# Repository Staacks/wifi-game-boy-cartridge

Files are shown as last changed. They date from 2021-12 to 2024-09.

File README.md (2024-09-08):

# wifi-game-boy-cartridge
A WiFi cartridge for the original Game Boy.

This open source and open hardware Game Boy cartridge uses an ESP8266 to allow WiFi access for custom Game Boy code. First demos include accessing Wikipedia articles from the Game Boy.

Details and instructions can be found on https://there.oughta.be/a/wifi-game-boy-cartridge and an overview is given in the following video:

Youtube Video: WiFi Game Boy Cartridge (https://youtu.be/QS4fzElm8zk)

Also, another article and video have been published on streaming video through this cartridge, which can be found at https://there.oughta.be/gta5-for-the-game-boy and in this video:

Youtube Video: Playing GTA5 on the original Game Boy (https://youtu.be/pX1opw_gsBs)

If you have pull-requests, bug reports or want to contribute new case designs, please do not hesitate to open an issue. For generic discussions, "show and tell" and if you are looking for support for something that is not a problem in the code here, I would recommend [r/thereoughtabe on reddit](https://www.reddit.com/r/thereoughtabe/).

<a href="https://www.buymeacoffee.com/there.oughta.be" target="_blank">Buy Me A Coffee</a>

# Important notice

Please read the resources above carefully and understand the limitations of this project. The brown-out issues have never been resolved and this is more a prove of concept than a consumer product. If you still want to try it yourself, please also note that rgbasm has changed a lot since this project was written and that its current version is no longer compatible with the asm files provided here. You may need to revert to rgbasm 0.5.2 to build them. 

# Short overview of the demos

As the number of demos keeps growing and some of them are just a quick experiment, you can find a few notes here:

## color-stream

This is the code for streaming videos to the Game Boy Color as shown in [in this little video](https://www.youtube.com/watch?v=kHexmGR_rPY). The code is supposed to detect if the cart is in a classic Game Boy (DMG) or a Game Boy color and both, the EEPROM code as well as the ESP8266 code should react accordingly. However, you have to use the right Python script, i.e. `video-stream` or `game-stream` for the original Game Boy or `color-stream` for a Game Boy color.

Note, that this has not been tested much and still has a few glitches. Also note, that I ran into an ffmpeg problem that prevented me from streaming screen captures on Linux (x11grab).

## serial

The oldest demo from the first video. When this is running, the Game Boy should show your IP address and you can connect to it with a telnet client. You can send text between Game Boy and PC and that's it. Note that there is an error in the way the data pins are initialized, causing them to run in open drain mode, which is ok, except for the highest bit which has an external pull-down and therefore stays low forever. For this demo, it does not matter because the character map does not have anything above the 7bit ASCII map anyways, but if you ever need the eighth bit, look at the streaming videos for how to initialize this correctly.

## stream

The streaming code on which the second video (playing GTA5) is based. It allows to show a video stream on the Game Boy and sends back key presses. You need to feed it with one of the Python scripts, either `video-stream.py` or `game-stream.py`. The buttons seem to generate a few ghost presses, which should be fixed by doing a few more readouts for the buttons (not tested).

## wiki

The Wikipedia demo from the first video. Once it has started, you can press start to get an on-screen keyboard, enter the title of a Wikipedia article and press start again to fetch an excerpt of that article. Pressing A shows you the remainder of the article, if any. Just like with the serial demo above, there is an error in the way the data pins are initialized, causing them to run in open drain mode, which is ok, except for the highest bit which has an external pull-down and therefore stays low forever. For this demo, it does not matter because the character map does not have anything above the 7bit ASCII map anyways, but if you ever need the eighth bit, look at the streaming videos for how to initialize this correctly.

# License
The code and the PCB design are released under the GNU General Public Licence 3. The only exception is the cartridge model for the 3d print, which is based on a [Game Boy cartridge by DomesticHacks on Thingiverse](https://www.thingiverse.com/thing:107841), which is released under a CC-BY-NC-SA license, so I have to publish my derived work under CC-BY-NC-SA, too.

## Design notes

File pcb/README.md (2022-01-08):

# Notes on the PCB design

There are two known possible issues in this design, which you should be aware of when ordering or manufacturing this PCB:
* Some of the 3V3 lines in the top left corner are done es part of an auto-fill area. This works perfectly in KiCad, is properly exported to Gerber files and also passes bug tests with the net list. However, when I ordered from aisler.net where you upload the KiCad file instead of Gerber files, the smaller 3V3 connections were lost. Since this worked in KiCad itself, I think it is a bug in Aisler's renderer, but unfortunately, they did not reply to my questions about this issue.
* I heavily use vias in solder pads. I read that this is bad practice as it might be a problem for automatic manufacturing processes, but fine for hand-soldering. As I did the latter I did not notice any problems, but you should be aware if you use a different process.

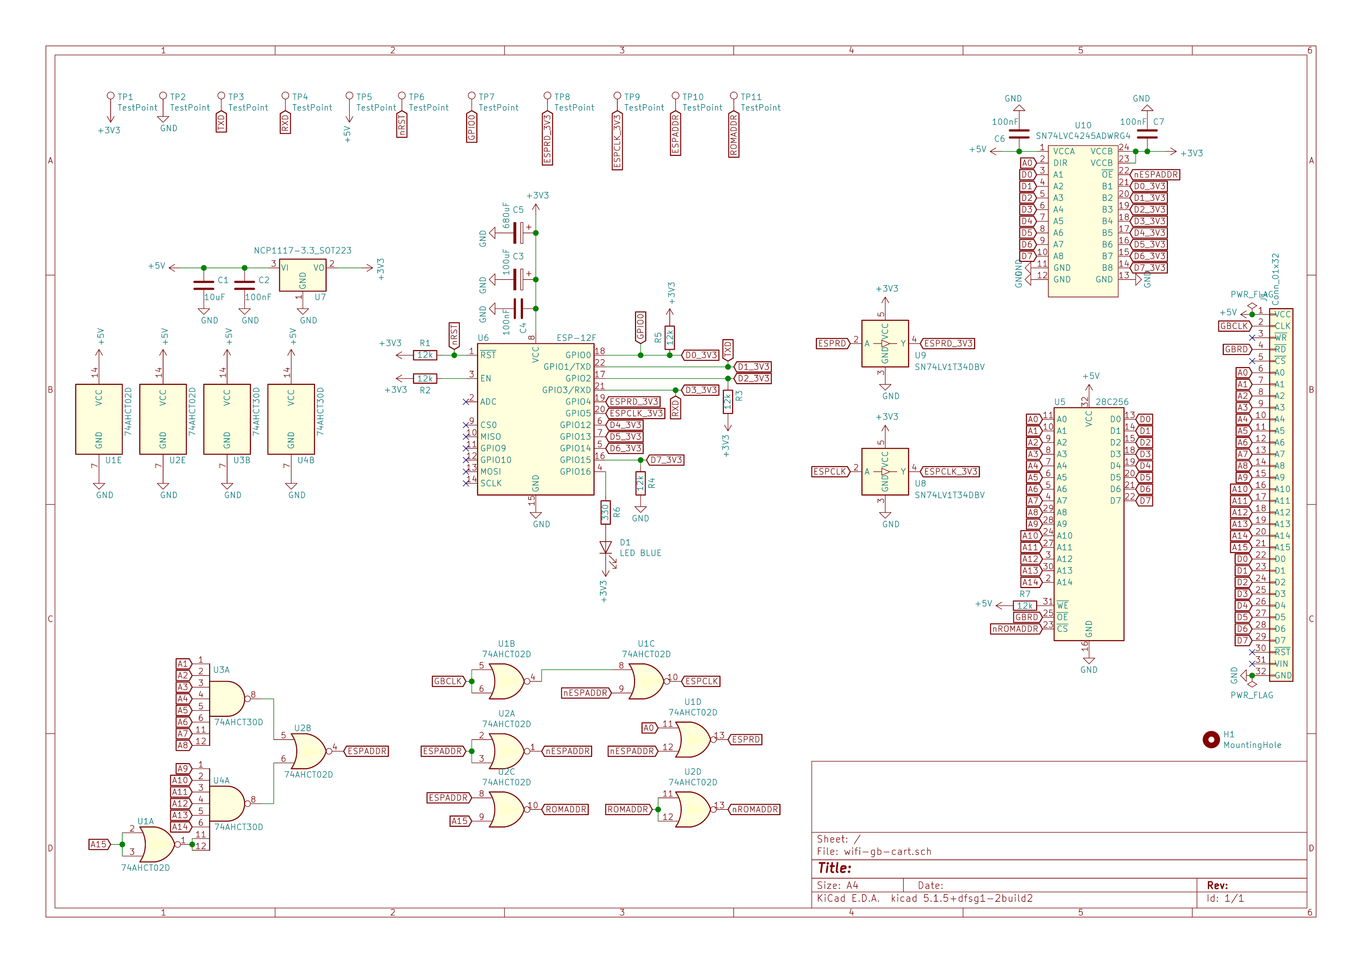
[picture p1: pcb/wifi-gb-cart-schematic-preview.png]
Preview of the schematic


# Licenses
This design is licensed under the GNU General Public License 3.0. See LICENSE file in this directory.

This project includes KiCad libraries and footprints from external sources with following license notices:

## From https://github.com/Gekkio/gb-hardware

This cartridge design uses the connector of Gekkio's GB-CART32K-A design, which is licensed under CC-BY-4.0.

## From https://github.com/adamgreig/agg-kicad

Copyright 2015, 2016 Adam Greig

Permission is hereby granted, free of charge, to any person obtaining a copy of this software and associated documentation files (the "Software"), to deal in the Software without restriction, including without limitation the rights to use, copy, modify, merge, publish, distribute, sublicense, and/or sell copies of the Software, and to permit persons to whom the Software is furnished to do so, subject to the following conditions:

The above copyright notice and this permission notice shall be included in all copies or substantial portions of the Software.

THE SOFTWARE IS PROVIDED "AS IS", WITHOUT WARRANTY OF ANY KIND, EXPRESS OR IMPLIED, INCLUDING BUT NOT LIMITED TO THE WARRANTIES OF MERCHANTABILITY, FITNESS FOR A PARTICULAR PURPOSE AND NONINFRINGEMENT. IN NO EVENT SHALL THE AUTHORS OR COPYRIGHT HOLDERS BE LIABLE FOR ANY CLAIM, DAMAGES OR OTHER LIABILITY, WHETHER IN AN ACTION OF CONTRACT, TORT OR OTHERWISE, ARISING FROM, OUT OF OR IN CONNECTION WITH THE SOFTWARE OR THE USE OR OTHER DEALINGS IN THE SOFTWARE.

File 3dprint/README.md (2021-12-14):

# Print parameters
I printed this with 0.1mm layer height with plain white PLA without supports.

# License
This model is based on a [Game Boy cartridge by DomesticHacks on Thingiverse](https://www.thingiverse.com/thing:107841) and accordingly retains a [CC-BY-NC-SA 4.0 licence](https://creativecommons.org/licenses/by-nc-sa/4.0/).

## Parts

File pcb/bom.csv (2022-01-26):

Query | Qty | Manufacturer | MPN | Octopart URL | Part Description | Description | Schematic Reference | Internal Part Number | Lifecycle | Lead Time | RoHS | Total Qty (@ Batch Size: 1) | SKU | SKU | SKU | SKU | SKU | Packaging | Packaging | Packaging | Packaging | Packaging | Unit Price (@ Batch Size: 1) | Unit Price (@ Batch Size: 1) | Unit Price (@ Batch Size: 1) | Unit Price (@ Batch Size: 1) | Unit Price (@ Batch Size: 1) | In Stock | In Stock | In Stock | In Stock | In Stock | MOQ | MOQ | MOQ | MOQ | MOQ | URL | URL | URL | URL | URL | Distributor [Lowest Price (Selected)] | SKU [Lowest Price (Selected)] | Packaging [Lowest Price (Selected)] | Unit Price (@ Batch Size: 1) [Lowest Price (Selected)] | Line Total [Lowest Price (Selected)] | Batch Total [Lowest Price (Selected)] | In Stock [Lowest Price (Selected)] | MOQ [Lowest Price (Selected)] | URL [Lowest Price (Selected)] | Notes
 |  |  |  |  |  |  |  |  |  |  |  |  | Digi-Key | Mouser | Newark | Onlinecomponents.com | RS Components | Digi-Key | Mouser | Newark | Onlinecomponents.com | RS Components | Digi-Key | Mouser | Newark | Onlinecomponents.com | RS Components | Digi-Key | Mouser | Newark | Onlinecomponents.com | RS Components | Digi-Key | Mouser | Newark | Onlinecomponents.com | RS Components | Digi-Key | Mouser | Newark | Onlinecomponents.com | RS Components
69802-432LF | 1 | Amphenol ICC / FCI | 69802-432LF | https://octopart.com/69802-432lf-amphenol+icc+%2F+fci-90340517 | Conn PLCC Socket SKT 32 POS 1.27mm Solder ST SMD T/R |  |  |  |  | 12w | Compliant | 1 | 609-4532-1-ND | 649-69802-432LF | 16M2200 | 69802-432LF | 1822967 | Cut Tape | Tape & Reel |  | Bulk |  | 1.68 | 1.66 | 0.541 |  |  | 3355 | 4990 | 424 | 4006 | 1617 | 1 | 1 | 1 | 390 | 5 | https://octopart.com/click/track?ai4=706&country=DE&ct=offers&ppid=90340517&sid=459&sig=0924f15&vpid=531335192 | https://octopart.com/click/track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 | https://octopart.com/click/track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 | https://octopart.com/click/track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 | https://octopart.com/click/track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 | Newark | 16M2200 |  | 0.541 | 0.541 | 0.541 | 424 | 1 | https://octopart.com/click/track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
AT28C256-15JU | 1 | Microchip | AT28C256-15JU | https://octopart.com/at28c256-15ju-microchip-77758239 | AT28C256-15JU Parallel EEPROM Memory, 256kbit, 150ns, 4.5 to 5.5 V 32-Pin PLCC |  |  |  | Production (Last Updated: 1 year ago) | 52w | Compliant | 1 | AT28C256-15JU-ND | 556-AT28C25615JU | 68T4337 | AT28C256-15JU | 1276569 | Tube | Tube |  | Bulk |  | 10.45 | 10.46 |  |  | 9.70502370395615 | 0 | 15 | 0 | 0 | 188 | 1 | 1 | 64 | 32 | 1 | https://octopart.com/click/track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 | https://octopart.com/click/track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 | https://octopart.com/click/track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 | https://octopart.com/click/track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 | https://octopart.com/click/track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 | RS Components | 1276569 |  | 9.70502370395615 | 9.70502370395615 | 9.70502370395615 | 188 | 1 | https://octopart.com/click/track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
74AHCT30D-Q100J | 2 | Nexperia | 74AHCT30D-Q100J | https://octopart.com/74ahct30d-q100j-nexperia-78749832 | 74AHCT Series 5 V Surface Mount 8-Input NAND Gate - SOIC-14 |  |  |  | Production (Last Updated: 18 hours ago) | 52w | Compliant | 2 | 74AHCT30D-Q100J-ND | 771-74AHCT30DQ100J |  |  |  | Tape & Reel | Tape & Reel |  |  |  |  | 0.65 |  |  |  | 0 | 623 |  |  |  | 2500 | 1 |  |  |  | https://octopart.com/click/track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 | https://octopart.com/click/track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 |  |  |  | Mouser | 771-74AHCT30DQ100J | Tape & Reel | 0.65 | 1.3 | 1.3 | 623 | 1 | https://octopart.com/click/track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
SN74AHCT02D | 2 | Texas Instruments | SN74AHCT02D | https://octopart.com/sn74ahct02d-texas+instruments-465348 | 4-ch, 2-input, 4.5-V to 5.5-V NOR gates with TTL-compatible CMOS inputs 14-SOIC -40 to 85 |  |  |  | Production (Last Updated: 1 week ago) | 6w | Compliant | 2 | 296-4634-5-ND | 595-SN74AHCT02D | 26AJ9118 |  |  | Tube | Tube |  |  |  | 1.16 | 1.15 | 1.78 |  |  | 343 | 968 | 0 |  |  | 1 | 1 | 1 |  |  | https://octopart.com/click/track?ai4=706&country=DE&ct=offers&ppid=465348&sid=459&sig=054b0ee&vpid=1996635 | https://octopart.com/click/track?ai4=706&country=DE&ct=offers&ppid=465348&sid=2401&sig=049629f&vpid=37843758 | https://octopart.com/click/track?ai4=706&country=DE&ct=offers&ppid=465348&sid=2402&sig=0316a07&vpid=702462753 |  |  | Mouser | 595-SN74AHCT02D | Tube | 1.15 | 2.3 | 2.3 | 968 | 1 | https://octopart.com/click/track?ai4=706&country=DE&ct=offers&ppid=465348&sid=2401&sig=049629f&vpid=37843758
RC1206FR-0712KL | 6 | Yageo | RC1206FR-0712KL | https://octopart.com/rc1206fr-0712kl-yageo-41455584 | Res Thick Film 1206 12K Ohm 1% 0.25W(1/4W) ±100ppm/C Pad SMD T/R |  |  |  |  | 20w | Compliant | 6 | 311-12.0KFRCT-ND | 603-RC1206FR-0712KL | 98K7634 |  |  | Cut Tape | Tape & Reel |  |  |  | 0.1 | 0.1 |  |  |  | 98698 | 24846 | 0 |  |  | 1 | 1 | 10 |  |  | https://octopart.com/click/track?ai4=706&country=DE&ct=offers&ppid=41455584&sid=459&sig=033d2b6&vpid=115263624 | https://octopart.com/click/track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 | https://octopart.com/click/track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 |  |  | Digi-Key | 311-12.0KFRCT-ND | Cut Tape | 0.1 | 0.6000000000000001 | 0.6000000000000001 | 98698 | 1 | https://octopart.com/click/track?ai4=706&country=DE&ct=offers&ppid=41455584&sid=459&sig=033d2b6&vpid=115263624
C1206C106K8PAC | 1 | KEMET | C1206C106K8PACTU | https://octopart.com/c1206c106k8pactu-kemet-8342310 | 1206 C 10uF Ceramic Multilayer Capacitor; 10 VDC; +85degC; X5R Dielec; +/-10% |  |  |  |  | 24w | Compliant | 1 | 399-C1206C106K8PAC7800CT-ND | 80-C1206C106K8P | 96K8340 | C1206C106K8PACTU | 148092P | Cut Tape | Tape & Reel |  | Bulk |  | 0.35 | 0.31 |  |  |  | 73059 | 17299 | 7660 | 0 | 29225 | 1 | 1 | 5 | 32 | 250 | https://octopart.com/click/track?ai4=706&country=DE&ct=offers&ppid=8342310&sid=459&sig=032318f&vpid=778087788 | https://octopart.com/click/track?ai4=706&country=DE&ct=offers&ppid=8342310&sid=2401&sig=0a64551&vpid=37843845 | https://octopart.com/click/track?ai4=706&country=DE&ct=offers&ppid=8342310&sid=2402&sig=030086b&vpid=73976561 | https://octopart.com/click/track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 | https://octopart.com/click/track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 | Mouser | 80-C1206C106K8P | Tape & Reel | 0.31 | 0.31 | 0.31 | 17299 | 1 | https://octopart.com/click/track?ai4=706&country=DE&ct=offers&ppid=8342310&sid=2401&sig=0a64551&vpid=37843845
C1206C104M5RACTU | 4 | KEMET | C1206C104M5RACTU | https://octopart.com/c1206c104m5ractu-kemet-129344 | 1206 C 100nF Ceramic Multilayer Capacitor; 50 VDC; +125degC; X7R Dielec; +/-20% |  |  |  |  | 52w | Compliant | 4 | 399-C1206C104M5RAC7800CT-ND | 80-C1206C104M5R | 14N2184 | C1206C104M5RACTU | 2053277 | Cut Tape | Tape & Reel |  | Bulk |  | 0.12 | 0.1 | 0.008 |  |  | 69939 | 49947 | 2519 | 0 | 2600 | 1 | 1 | 1 | 8000 | 100 | https://octopart.com/click/track?ai4=706&country=DE&ct=offers&ppid=129344&sid=459&sig=0316d49&vpid=778087758 | https://octopart.com/click/track?ai4=706&country=DE&ct=offers&ppid=129344&sid=2401&sig=09e4eaf&vpid=44737023 | https://octopart.com/click/track?ai4=706&country=DE&ct=offers&ppid=129344&sid=2402&sig=0e80658&vpid=16453344 | https://octopart.com/click/track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 | https://octopart.com/click/track?ai4=706&country=DE&ct=offers&ppid=129344&sid=10022&sig=02caed9&vpid=694088864 | Newark | 14N2184 |  | 0.008 | 0.032 | 0.032 | 2519 | 1 | https://octopart.com/click/track?ai4=706&country=DE&ct=offers&ppid=129344&sid=2402&sig=0e80658&vpid=16453344
SN74LVC4245ADWRG4 | 1 | Texas Instruments | SN74LVC4245ADWRG4 | https://octopart.com/sn74lvc4245adwrg4-texas+instruments-7119357 | Octal Bus Transceiver And 3.3-V To 5-V Shifter With 3-State Outputs 24-SOIC -40 to 85 |  |  |  | Production (Last Updated: 1 week ago) | 20w | Compliant | 1 | 296-48964-1-ND | 595-74LVC4245ADWRG4 |  |  |  | Cut Tape | Tape & Reel |  |  |  | 1.64 | 1.64 |  |  |  | 1145 | 191 |  |  |  | 1 | 1 |  |  |  | https://octopart.com/click/track?ai4=706&country=DE&ct=offers&ppid=7119357&sid=459&sig=031f038&vpid=477161524 | https://octopart.com/click/track?ai4=706&country=DE&ct=offers&ppid=7119357&sid=2401&sig=09ef8d3&vpid=94925989 |  |  |  | Digi-Key | 296-48964-1-ND | Cut Tape | 1.64 | 1.64 | 1.64 | 1145 | 1 | https://octopart.com/click/track?ai4=706&country=DE&ct=offers&ppid=7119357&sid=459&sig=031f038&vpid=477161524
SN74LV1T34DBVRG4 | 2 | Texas Instruments | SN74LV1T34DBVRG4 | https://octopart.com/sn74lv1t34dbvrg4-texas+instruments-91780194 | Single Power Supply BUFFER Logic Level Shifter (no enable) 5-SOT-23 -40 to 125 |  |  |  | Production (Last Updated: 1 week ago) | 35w | Non-Compliant | 2 | 296-SN74LV1T34DBVRG4DKR-ND | 595-SN74LV1T34DBVRG4 |  |  |  | Custom Reel | Tape & Reel |  |  |  | 0.64 | 0.64 |  |  |  | 0 | 3 |  |  |  | 1 | 1 |  |  |  | https://octopart.com/click/track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 | https://octopart.com/click/track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 |  |  |  | Mouser | 595-SN74LV1T34DBVRG4 | Tape & Reel | 0.64 | 1.28 | 1.28 | 3 | 1 | https://octopart.com/click/track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
NCP1117IST33T3G | 1 | onsemi | NCP1117IST33T3G | https://octopart.com/ncp1117ist33t3g-onsemi-117063396 | LDO Regulator, 1 A, Fixed and Adjustable, Positive Vout: 3.3 V |  |  |  |  | 48w |  | 1 | 488-NCP1117IST33T3GCT-ND | 863-NCP1117IST33T3G | 50AJ5825 |  | 2296355 | Cut Tape | Tape & Reel |  |  |  | 0.6 | 0.6 |  |  |  | 0 | 0 | 3975 |  | 0 | 1 | 1 | 5 |  | 10 | https://octopart.com/click/track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 | https://octopart.com/click/track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 | https://octopart.com/click/track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 |  | https://octopart.com/click/track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 | Digi-Key | 488-NCP1117IST33T3GCT-ND | Cut Tape | 0.6 | 0.6 | 0.6 | 0 | 1 | https://octopart.com/click/track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
5015 | 7 | Keystone | 5015 | https://octopart.com/5015-keystone-3822 | MS27478 - Connectors Receptacle Electrical Solder Mounting Solder Type Hermetic Seal 38999 Series II |  |  |  |  | 12w | Compliant | 7 | 36-5015CT-ND | 534-5015 | 50B4581 |  |  | Cut Tape | Tape & Reel |  |  |  | 0.45 | 0.45 | 0.67 |  |  | 5192104 | 2055416 | 11335 |  |  | 1 | 1 | 1 |  |  | https://octopart.com/click/track?ai4=706&country=DE&ct=offers&ppid=3822&sid=459&sig=04fb0c0&vpid=212427660 | https://octopart.com/click/track?ai4=706&country=DE&ct=offers&ppid=3822&sid=2401&sig=0e2f561&vpid=37763329 | https://octopart.com/click/track?ai4=706&country=DE&ct=offers&ppid=3822&sid=2402&sig=0b853ff&vpid=2982736 |  |  | Digi-Key | 36-5015CT-ND | Cut Tape | 0.45 | 3.15 | 3.15 | 5192104 | 1 | https://octopart.com/click/track?ai4=706&country=DE&ct=offers&ppid=3822&sid=459&sig=04fb0c0&vpid=212427660
TAJE687M010RNJV | 1 | KYOCERA AVX | TAJE687M010RNJV | https://octopart.com/taje687m010rnjv-kyocera+avx-122089020 | Cap Tant Solid 680uF 10V E CASE 20% (7.3 X 4.3 X 4.1mm) Inward L SMD 7343-43 0.4 Ohm 125C T/R |  |  |  | Production (Last Updated: 2 years ago) | 35w | Non-Compliant | 1 | 478-TAJE687M010RNJVTR-ND | 581-TAJE687M010RNJV | 13AC9452 |  |  | Tape & Reel | Tape & Reel |  |  |  |  | 3.7 |  |  |  | 0 | 0 | 0 |  |  | 400 | 1 | 400 |  |  | https://octopart.com/click/track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 | https://octopart.com/click/track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 | https://octopart.com/click/track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 |  |  | Mouser | 581-TAJE687M010RNJV | Tape & Reel | 3.7 | 3.7 | 3.7 | 0 | 1 | https://octopart.com/click/track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
TAJB107M010RNJ | 1 | AVX | TAJB107M010RNJ | https://octopart.com/tajb107m010rnj-avx-10552444 | Cap Tant Solid 100uF 10V B CASE 20% (3.5 X 2.8 X 1.9mm) SMD 3528-21 1.4 Ohm 125A HA T/R |  |  |  | Production (Last Updated: 2 years ago) | 30w | Compliant | 1 | 478-5801-1-ND | 581-TAJB107M010R | 15P3056 |  | 1360118 | Cut Tape | Tape & Reel |  |  |  | 0.62 | 0.82 |  |  |  | 0 | 0 | 0 |  | 960 | 1 | 1 | 5 |  | 20 | https://octopart.com/click/track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 | https://octopart.com/click/track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 | https://octopart.com/click/track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 |  | https://octopart.com/click/track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 | Digi-Key | 478-5801-1-ND | Cut Tape | 0.62 | 0.62 | 0.62 | 0 | 1 | https://octopart.com/click/track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
CRGCQ1206J330R | 1 | TE Connectivity | CRGCQ1206J330R | https://octopart.com/crgcq1206j330r-te+connectivity-91018326 | Res Thick Film 1206 330 Ohm 5% 0.25W(1/4W) ±100ppm/C Pad SMD Automotive T/R |  |  |  | Production (Last Updated: 1 week ago) | 21w | Compliant | 1 | A130174CT-ND | 279-CRGCQ1206J330R | 61AC6733 | CRGCQ1206J330R |  | Cut Tape | Tape & Reel |  | Bulk |  | 0.1 | 0.1 | 0.029 |  |  | 33157 | 3438 | 3180 | 0 |  | 1 | 1 | 1 | 5000 |  | https://octopart.com/click/track?ai4=706&country=DE&ct=offers&ppid=91018326&sid=459&sig=0358dc5&vpid=475509225 | https://octopart.com/click/track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 | https://octopart.com/click/track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 | https://octopart.com/click/track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 |  | Newark | 61AC6733 |  | 0.029 | 0.029 | 0.029 | 3180 | 1 | https://octopart.com/click/track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
156120BS75000 | 1 | Würth Elektronik | 156120BS75000 | https://octopart.com/156120bs75000-w%C3%BCrth+elektronik-71241453 | Led, Blue, 50MCD, 470NM, 1206 |  |  |  |  | 23w | Non-Compliant | 1 | 732-11418-1-ND | 710-156120BS75000 | 22AC3288 |  | 9008921P | Cut Tape | Tape & Reel |  |  |  | 0.35 | 0.35 | 0.398 |  |  | 5492 | 719 | 1214 |  | 1500 | 1 | 1 | 1 |  | 250 | https://octopart.com/click/track?ai4=706&country=DE&ct=offers&ppid=71241453&sid=459&sig=04af43a&vpid=423421451 | https://octopart.com/click/track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 | https://octopart.com/click/track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 |  | https://octopart.com/click/track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 | Digi-Key | 732-11418-1-ND | Cut Tape | 0.35 | 0.35 | 0.35 | 5492 | 1 | https://octopart.com/click/track?ai4=706&country=DE&ct=offers&ppid=71241453&sid=459&sig=04af43a&vpid=423421451
ESP-12F | 1 | Ai-Thinker | ESP-12F | https://octopart.com/esp-12f-ai-thinker-121417371 |  |  |  |  |  |  |  | 1

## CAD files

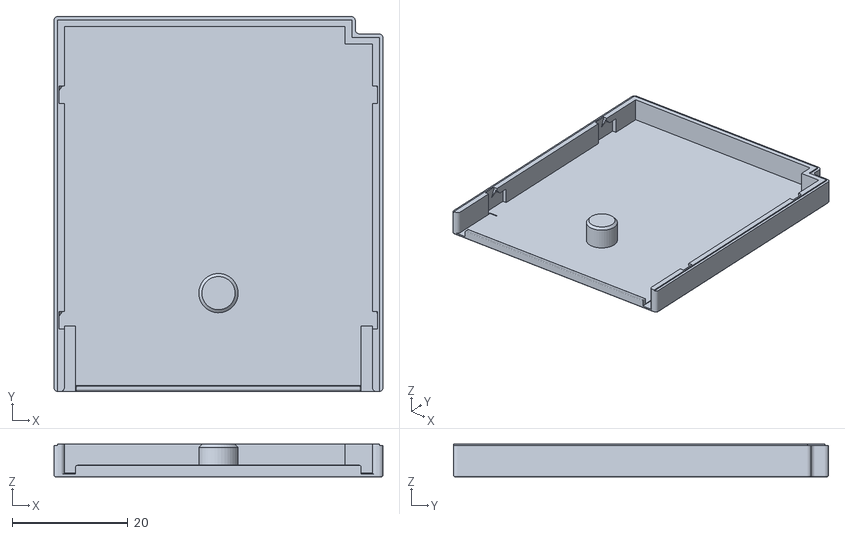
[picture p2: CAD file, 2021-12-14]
3dprint/bottom.stl
56.9 x 64.8 x 5.70

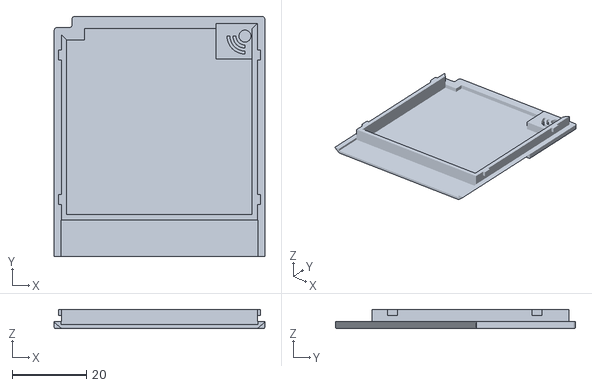
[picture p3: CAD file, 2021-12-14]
3dprint/top.stl
56.9 x 64.8 x 5.14

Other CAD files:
3dprint/bottom.blend
3dprint/top.blend

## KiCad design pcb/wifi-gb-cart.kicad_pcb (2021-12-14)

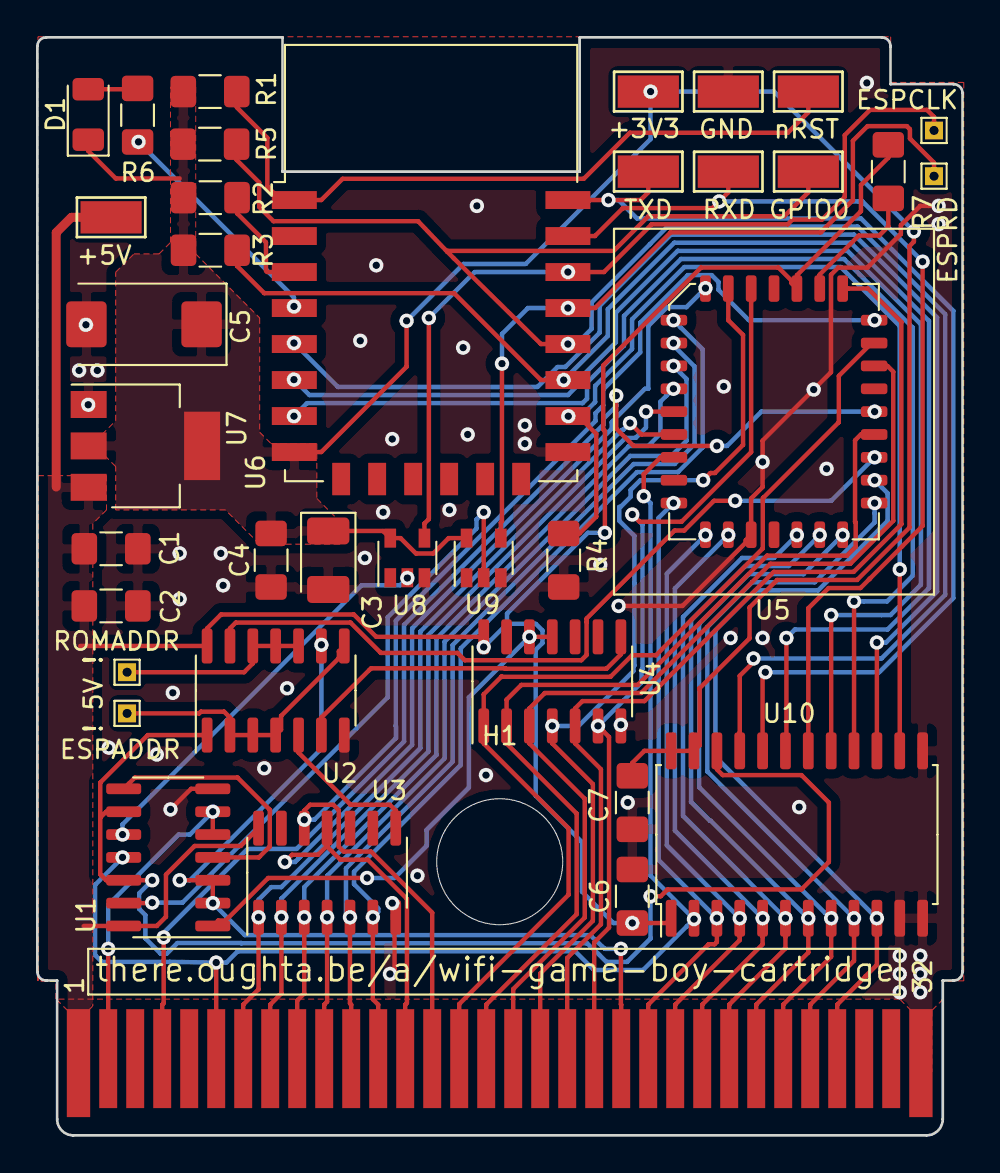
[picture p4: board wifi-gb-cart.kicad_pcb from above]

Board: 2 copper layers, 51.4 x 61.0 mm, 38 parts (0 on the bottom side), 54 nets.

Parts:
+3V3, +5V: TestPoint; TestPoint_Keystone_5015_Micro-Minature
C1: 10uF; C_1206_3216Metric_Pad1.42x1.75mm_HandSolder
C2, C4, C6, C7: 100nF; C_1206_3216Metric_Pad1.42x1.75mm_HandSolder
C3: 100uF; CP_EIA-3528-12_Kemet-T_Pad1.50x2.35mm_HandSolder
C5: 680uF; CP_EIA-7343-43_Kemet-X_Pad2.25x2.55mm_HandSolder
D1: LED BLUE; LED_1206_3216Metric
ESPADDR: TestPoint; TestPoint_THTPad_1.0x1.0mm_Drill0.5mm
ESPCLK: TestPoint; TestPoint_THTPad_1.0x1.0mm_Drill0.5mm
ESPRD: TestPoint; TestPoint_THTPad_1.0x1.0mm_Drill0.5mm
GND: TestPoint; TestPoint_Keystone_5015_Micro-Minature
GPIO0: TestPoint; TestPoint_Keystone_5015_Micro-Minature
H1: MountingHole; MountingHole_7mm
J1: Conn_01x32; cartridge_PCBedge
R1, R2, R3, R4, R5, R7: 12k; R_1206_3216Metric_Pad1.42x1.75mm_HandSolder
R6: 330; R_1206_3216Metric_Pad1.42x1.75mm_HandSolder
ROMADDR: TestPoint; TestPoint_THTPad_1.0x1.0mm_Drill0.5mm
RXD: TestPoint; TestPoint_Keystone_5015_Micro-Minature
TXD: TestPoint; TestPoint_Keystone_5015_Micro-Minature
U1, U2: 74AHCT02D; SOIC-14_3.9x8.7mm_P1.27mm
U3, U4: 74AHCT30D; SOIC-14_3.9x8.7mm_P1.27mm
U5: 28C256; PLCC-32_11.4x14.0mm_P1.27mm_SOCKET
U6: ESP-12F; ESP-12E
U7: NCP1117-3.3_SOT223; SOT-223-3_TabPin2
U8, U9: SN74LV1T34DBV; SOT-23-5
U10: SN74LVC4245ADWRG4; SOIC-24W_7.5x15.4mm_P1.27mm
nRST: TestPoint; TestPoint_Keystone_5015_Micro-Minature

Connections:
+3V3: +3V3.1, C3.1, C4.1, C5.1, C7.1, D1.1, R1.1, R2.2, R3.1, R5.1, U6.8, U7.2, U8.5, U9.5, U10.23, U10.24
+5V: +5V.1, C1.1, C2.1, C6.1, J1.1, R7.2, U1.14, U2.14, U3.14, U4.14, U5.32, U7.3, U10.1
A0: J1.6, U1.11, U5.11, U10.2
A1: J1.7, U3.1, U5.10
A2: J1.8, U3.2, U5.9
A3: J1.9, U3.3, U5.8
A4: J1.10, U3.4, U5.7
A5: J1.11, U3.5, U5.6
A6: J1.12, U3.6, U5.5
A7: J1.13, U3.11, U5.4
A8: J1.14, U3.12, U5.29
A9: J1.15, U4.1, U5.28
A10: J1.16, U4.2, U5.24
A11: J1.17, U4.3, U5.27
A12: J1.18, U4.4, U5.3
A13: J1.19, U4.5, U5.30
A14: J1.20, U4.6, U5.2
A15: J1.21, U1.2, U1.3, U2.9
D0: J1.22, U5.13, U10.3
D0_3V3: GPIO0.1, R5.2, U6.18, U10.21
D1: J1.23, U5.14, U10.4
D1_3V3: TXD.1, U6.22, U10.20
D2: J1.24, U5.15, U10.5
D2_3V3: R3.2, U6.17, U10.19
D3: J1.25, U5.18, U10.6
D3_3V3: RXD.1, U6.21, U10.18
D4: J1.26, U5.19, U10.7
D4_3V3: U6.6, U10.17
D5: J1.27, U5.20, U10.8
D5_3V3: U6.7, U10.16
D6: J1.28, U5.21, U10.9
D6_3V3: U6.5, U10.15
D7: J1.29, U5.22, U10.10
D7_3V3: R4.2, U6.16, U10.14
ESPADDR: ESPADDR.1, U2.2, U2.3, U2.4, U2.8
ESPCLK: U1.10, U8.2
ESPCLK_3V3: ESPCLK.1, U6.20, U8.4
ESPRD: U1.13, U9.2
ESPRD_3V3: ESPRD.1, U6.19, U9.4
GBCLK: J1.2, U1.5, U1.6
GBRD: J1.4, U5.25
GND: C1.2, C2.2, C3.2, C4.2, C5.2, C6.2, C7.2, GND.1, J1.32, R4.1, U1.7, U2.7, U3.7, U4.7, U5.16, U6.15, U7.1, U8.3, U9.3, U10.11, U10.12, U10.13
unnamed: D1.2, R6.1
unnamed: R2.1, U6.3
unnamed: R6.2, U6.4
unnamed: R7.1, U5.31
unnamed: U1.1, U4.11, U4.12
unnamed: U1.4, U1.8
unnamed: U2.5, U3.8
unnamed: U2.6, U4.8
ROMADDR: ROMADDR.1, U2.10, U2.11, U2.12
nESPADDR: U1.9, U1.12, U2.1, U10.22
nROMADDR: U2.13, U5.23
nRST: R1.2, U6.1, nRST.1

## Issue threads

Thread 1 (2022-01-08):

Gerbers don't have a NC drill file!

GeorgeRudolf, 2022-01-08:
No drill output has been generated in KiCad - using the Gerbers currently hosted on github will result in failure.

Staacks, 2022-01-08:
Thanks, I have added those now.

Note, that I had generated the Gerber files without testing them as I ordered my PCBs from Aisler and they directly use the KiCad project file. I just placed an order with JLCPCB now using the Gerber files, so if you want a confirmation first, you can wait until I received the result.

Another, entirely unrelated note, but as you seem on the verge of building it now before I can give an update on this issue, you might find this detail interesting:
I am currently looking a bit into the power issues I mentioned at the end of the video and it seems to be two-fold: One issue is a voltage drop for the Game Boy when the ESP uses WiFi intermittently, which seems to be less of an issue when the WiFi usage is more or less constant (like when streaming video in my upcoming follow up). The other issue is that the voltage regulator I used has a rather high dropout voltage and fails to deliver the 3.3V if the batteries are not 100% full or if NiMh rechargables are being used. I am looking for a pin-compatible alternative right now, but unfortunately as is the case so often at the moment, most are not available.

GeorgeRudolf, 2022-01-11:
What's your test platform? DMG, MGB, or CGB?
I can have a look at the power rails on DMG and on a GB Boy Colour, when I get it built.

Unfortunately, yes, sourcing regulators has become a nuisance.

Staacks, 2022-01-11:
I only have a DMG. The problem has two sides:
- When I turn on the Game Boy, the Nintendo logo is often surrounded by glitches that form a repeating pattern along the tile grid. I think this is due to a voltage drop as the ESP starts while the Game Boys voltage supply is not entirely stabilized, corrupting some of its memory. I think that this would require delaying either the start of the ESP or the Game Boy (via Reset pin?), but this problem is mostly cosmetic as I do not see any problems later and the glitches disappear after the logo screen.
- If the battery voltage is a bit too low (and I am talking about something like 1.48 V per battery), the ESP does not boot reliably. If it is even lower (especially with NiMh batteries), I cannot get the ESP to boot at all. I have not yet measured the actual voltage at the cartridge at this point (yeah, it's a matter of seconds, but I do not have the Game Boy at hand right now), but I think that I underestimated how much the 5V from the Game Boy actually depend on the source voltage and that the dropout voltage of the NCP1117 is just too high to sustain a proper voltage for the ESP in that case. After a quick search I now ordered a few AP7361C-33ER as a pin-compatible replacement with lower drop-out voltage.
-

Staacks, 2022-01-11:
Just realized, that this should probably get it's own issue, so I copied it here: https://github.com/Staacks/wifi-game-boy-cartridge/issues/2

Closed 2022-01-08.

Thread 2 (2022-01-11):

Power instabilities

Staacks, 2022-01-11:
The problem has two sides:

- When I turn on the Game Boy, the Nintendo logo is often surrounded by glitches that form a repeating pattern along the tile grid. I think this is due to a voltage drop as the ESP starts while the Game Boys voltage supply is not entirely stabilized, corrupting some of its memory. I think that this would require delaying either the start of the ESP or the Game Boy (via Reset pin?), but this problem is mostly cosmetic as I do not see any problems later and the glitches disappear after the logo screen.
- If the battery voltage is a bit too low (and I am talking about something like 1.48 V per battery), the ESP does not boot reliably. If it is even lower (especially with NiMh batteries), I cannot get the ESP to boot at all. I have not yet measured the actual voltage at the cartridge at this point (yeah, it's a matter of seconds, but I do not have the Game Boy at hand right now - I will do this later), but I think that I underestimated how much the 5V from the Game Boy actually depend on the source voltage and that the dropout voltage of the NCP1117 is just too high to sustain a proper voltage for the ESP in that case. After a quick search I now ordered a few AP7361C-33ER as a pin-compatible replacement with lower drop-out voltage.

GeorgeRudolf, 2022-01-11:
Just measured on a random DMG here - VBat 3.82V at no load, 3.79V while booting, Vcc at cart slot solid at 5.02V with one of those horrible 25-in-1 carts stabbed in (flashROM+MBC5+SRAM). You might need to add a voltage monitor to the design, so that !RESET is held low until 3.3 is stable. Luckily that's usually just one extra SOT-23.

Staacks, 2022-01-11:
You are right. I just measured and got 4.95V for all batteries I tried - Also in the case of the NiMh with 4x 1.2V.

However, when I use my WiFi cartridge, the voltage in the latter case drops down to 3V. The Nintendo logo moves properly (although the contrast has to be adjusted in this case) and the ESP just won't start. Is this the load of the ESP (which presumably just keeps "trying" to boot) on the Game Boy in combination with the low voltage from the batteries? I think a delayed start of the Game Boy would only help with the visible memory glitches.

Franticware, 2022-01-28:
Hi, this is what I am using to stepping down voltage very efficiently:
https://www.aliexpress.com/item/33014445559.html

Franticware, 2022-01-28:
Hi, this is what I am using to stepping down voltage very efficiently, it should work nicely for this project:
https://www.aliexpress.com/item/32880983608.html
(I suggested this during your youtube Q&A in a form of a question as phrtza)

Staacks, 2022-01-30:
Thanks. Not exactly a drop-in replacement. :)
I think it is time that I read up on how these things work and how to properly use them instead of just spraying the board with a few capacitors to both sides.

Franticware, 2022-01-30:
Right, you can't do it without an inductor when you want efficiency. Also please note the row of precision resistors used to select output voltage. Maybe the easiest way is to just buy a few of these modules to harvest the parts. I never looked for schematics nor reverse-engineered the module, but it seems straightforward. I used is as is for my own ESP8266 project to convert power from 7.2V (2x 18650) to 3.3V.
Also, it has enable pin that could theoretically be used for delayed power up of the more power hungry components.
Another note, off topic: You mentioned potential replacement for the EPROM/EEPROM with Flash. Flash chips with parallel interface exist, this one for example is used in Mega Drive flash carts by krikzz: http://www.farnell.com/datasheets/40281.pdf

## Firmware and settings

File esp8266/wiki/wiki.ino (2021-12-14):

#include <ESP8266WiFi.h>
#include <WiFiClientSecure.h>
#include <ESP8266HTTPClient.h>
#include <ArduinoJson.h>

#include "secrets.h" 
const char* ssid = SECRET_SSID;
const char* pass = SECRET_PASS;

const char * apiURL = "https://en.wikipedia.org/w/api.php";

const uint16_t dataMask = 0xf00f;
const byte pinEspRd = 4;
const uint16_t pinEspRdMask = 1 << pinEspRd;
const byte pinEspClk = 5;
const uint16_t pinEspClkMask = 1 << pinEspClk;
const byte pinLED = 16;

char outbuffer[256];
volatile byte outindex;
volatile bool outFilled;
char inbuffer[256];
volatile byte inindex;
volatile bool inFilled;

char resultData[4096];
char * resultPosition;
boolean resultPending = false;

char serialBuffer[256];
byte serialIndex = 0;

void setup() {  
  delay(500); //Just to avoid anything triggering during the somewhat "electrically turbulent" start.
  
  //Init buffers to terminal character
  outbuffer[0] = '\0';
  outindex = 0;
  outFilled = false;
  inbuffer[0] = '\0';
  inindex = 0;
  inFilled = false;
  
  //Setup pins
  for (int i = 0; i < 16; i++) {
    if ((0x0001 << i) & dataMask) {
      pinMode(i, INPUT_PULLUP);
    }
  }
  
  //Other pins with helper functions for readability.
  pinMode(pinEspRd, INPUT);
  pinMode(pinEspClk, INPUT);
  pinMode(pinLED, OUTPUT);

  //Interrupts
  //DO NOT TOUCH espRd INTERRUPTS!
  //Especially the logic of enabling the GPIO output in response to the interrupts
  //must match the behavior of the Game Boy program. The Game Boy may never try to
  //write to the ESP while the GPIO output is enabled or we will get bus contention
  //(i.e. a short circuit that might damage something)
  attachInterrupt(digitalPinToInterrupt(pinEspClk), espClkFall, FALLING);
  attachInterrupt(digitalPinToInterrupt(pinEspRd), espRdFall, FALLING);
}

//Get CPU cycle, based on https://sub.nanona.fi/esp8266/timing-and-ticks.html
static inline int32_t asm_ccount(void) {
    int32_t r;
    asm volatile ("rsr %0, ccount" : "=r"(r));
    return r;
}

//Variables controlling interrupt logic
volatile int32_t lastRd = 0;  //Number of clock cycles on the last ESPRD fall used to reject triggers of espClkFall while reading espRdFall is doing its thing.
volatile int32_t lastClk = 0; //Number of clock cycles on the last ESPCLK fall used to reject the trigger on the second event.
volatile boolean readingFromESP = false;

//DO NOT TOUCH INTERRUPTS unless you know what you are doing! (see above)
//When the ESPRD input rises, the Game Boy wants to read from the ESP
//We are way to slow to respond to the first read request and the Game Boy
//will have to drop the first response as it will be undefined. However, we
//will use the read request as a trigger to output the next character and
//the Game Boy just needs to read slow enough so the ESP can keep up.
//When we set \0 as output, this is the last character of our data stream,
//but we disable the output when the rd line rises after that, because that
//is when the Game Boy has seen this \0 and also expects us to stop.
ICACHE_RAM_ATTR void espRdFall() {
  lastRd = asm_ccount();
  if (!readingFromESP) {
    //First read attempt. Enable output and start with first character
    readingFromESP = true;
    GPES = dataMask; //Enable all data pins
  }
  if (outFilled) {
    //Send current character and move to the next one
    char data = outbuffer[outindex++];
    uint32_t pinData = ((data & 0x00f0) << 8) | (data & 0x0f);
    GPOS = pinData & dataMask;
    GPOC = ~pinData & dataMask;
    if (data == '\0') {
      outFilled = false;
    }
  } else if (outindex == 0) {
    //There is no data to send, but we need to send \0 anyways, so the Game Boy knows that we are done.
    GPOC = dataMask;
    outindex++;
  } else {
    //The \0 has been sent last time. Let's turn off the output and end this transfer
    GPEC = dataMask; //Disable all data pins
    readingFromESP = false;
    outindex = 0;
    return;
  }
}

//DO NOT TOUCH INTERRUPTS unless you know what you are doing! (see above)
//The ESPCLK falls in the middle of a R/W operation. If the Game Boy is
//reading from the ESP, this is handled in espRdRise, which sets
//readingFromESP = true. In this case, this interrupt here will be ignored.
//If the Game Boy tries to write to the ESP, however, everything becomes a
//bit more tricky as the interrupt delay is a multiple of a single memory
//access cycle. Therefore, the Game Boy will do three consecutive write
//attempts at equidistant intervals. We will use the first two to figure out
//the timing of the write attempts (which will include our own interrupt
//delay), so we can try to exactly intercept the third attempt.
//We also need to ignore too fast interrupt triggers, because there is a
//short additional spike of ESPCLK at the end of each cycle (although I
//doubt that it can trigger the interrupt) and we will not try to directly
//catch subsequent write attempts as we can be lucky if this method is
//precise enough to capture the third write :)
ICACHE_RAM_ATTR void espClkFall() {
  int32_t clk = asm_ccount();
  if (readingFromESP)
    return;
  if ((uint32_t)(clk - lastRd) < 800) //Reject if (dt < 10µs), the ESP8266 has an 80MHz clock, so one cycle is 12.5ns
    //The thing is that even starting the interrupt routine can take several µs, so if this has been triggered together with the last call to espRdFall, an unwanted call might come in still a few µs after that
    return;
  if ((uint32_t)(clk - lastClk) < 2400) //Reject if (dt < 30µs), the ESP8266 has an 80MHz clock, so one cycle is 12.5ns
    //We don't want to trigger again on the second write
    return;

  //Wait for rising edge with a timeout, so this does not block forever if we miss it
  while ((uint32_t)(asm_ccount() - clk) < 1400) {
    if (GPI & pinEspClkMask)
      break;
  }
  //Wait for falling edge. (No need for a timeout. ESPRD only stays HIGH for a few 100ns.
  while (GPI & pinEspClkMask) {
    //NOOP
  }
  uint32_t gpi = GPI; //Catch the new value
  
  if (!inFilled) {
    //Only accept new data if the buffer is not already filled
    char c = ((gpi & 0xf000) >> 8) | (gpi & 0x0f);
    inbuffer[inindex] = c;
    if (c == '\0') {
      if (inindex > 0)
        inFilled = true;
    } else
      inindex++;
  }
  lastClk = clk;
  
}

void maintainWifi() {
  int status = WiFi.status();
  while (status != WL_CONNECTED) {
    digitalWrite(pinLED, LOW);

    status = WiFi.begin(ssid, pass);

    int pauses = 0;
    while (status != WL_CONNECTED && pauses < 20) {
      delay(500);
      pauses++;
      if (pauses % 2 == 0)
        digitalWrite(pinLED, LOW);
      else
        digitalWrite(pinLED, HIGH);
      status = WiFi.status();
    }
  
    digitalWrite(pinLED, LOW);

    if (!outFilled && outindex == 0) {
      String ip = WiFi.localIP().toString();
      outbuffer[outindex++] = 'I';
      outbuffer[outindex++] = 'P';
      outbuffer[outindex++] = ':';
      outbuffer[outindex++] = ' ';
      for (uint8_t i = 0; i < ip.length(); i++) {
        outbuffer[outindex++] = ip[i];
      }
      outbuffer[outindex++] = '\0';
      outindex = 0;
      outFilled = true;
    }
  }
}

void handleDataFromGameBoy() {
  if (inFilled) {
    if (strcmp(inbuffer, "+") == 0) {
      if (resultPending) {
        strncpy(outbuffer, resultPosition, 241);
        if (outbuffer[240] != '\0') {
          resultPosition += 240;
          outbuffer[240] = '\0';
        } else
          resultPending = false;
        outindex = 0;
        outFilled = true;
      }
    } else {
      char url[256];

      //Replace spaces with underscores
      for (char * i = inbuffer; *i != '\0'; i++)
        if (*i == ' ')
          *i = '_';
          
      strcpy(url, apiURL);
      strcat(url, "?action=query&format=json&titles=");
      strcat(url, inbuffer);
      strcat(url, "&prop=extracts&exintro&explaintext");
  
      WiFiClientSecure client;
      client.setInsecure();
      HTTPClient http;
      http.useHTTP10(true);
      http.begin(client, url);
      int httpCode = http.GET();
      if (httpCode == 200) {
        DynamicJsonDocument doc(4096);
        DeserializationError error = deserializeJson(doc, http.getStream());
        if (error) {
          strcpy(outbuffer, "JSON error: ");
          strcat(outbuffer, error.c_str());
          outindex = 0;
          outFilled = true;
        } else {
          JsonObject pages = doc["query"]["pages"];
          JsonObject::iterator it = pages.begin();
          if (it->key() == "-1")
            strcpy(outbuffer, "Not found.");
          else {
            strncpy(resultData, it->value()["extract"], 4096);
            resultPending = true;
            resultPosition = resultData;
            strncpy(outbuffer,resultPosition, 241); //240+null, use multiple of 20 to align with screen width
            if (outbuffer[240] != '\0') {
              resultPosition += 240;
              outbuffer[240] = '\0';
            } else
              resultPending = false;
          }
          outindex = 0;
          outFilled = true;
        }
      } else {
        char code[4];
        itoa(httpCode, code, 10);
        strcpy(outbuffer, "Error: ");
        strcat(outbuffer, code);
        outindex = 0;
        outFilled = true;
      }
      http.end();
    }

    inindex = 0;
    inFilled = false;
  }
}

void loop() {
  maintainWifi();
  handleDataFromGameBoy();
}

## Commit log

2021-12-14 Initial commit.
    [bottom.blend, bottom.stl, top.blend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]
2021-12-14 Remove unused KiCad library.
2021-12-15 Add PNG preview of PCB schematic.
2022-01-08 Add NC drill files to PCB gerber folder. (Fixing issue #1)
    [wifi-gb-cart-B_Cu.gbr, wifi-gb-cart-B_Mask.gbr, wifi-gb-cart-B_Paste.gbr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]
2022-01-26 Add code for video streaming to the Game Boy Color. This has not been tested much and still has a few glitches.
    [color-stream.ino]
2022-01-26 Add BOM in CSV format. (issue #3)
    [bom.csv]
2022-02-09 Several small improvements to GBC streaming: - Slightly more wiggle room in interrupts for more robust timing. - Reduce WiFi TX power (this fixes most of the visual glitches and somewhat improves the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
    [color-stream.ino]
2025-01-03 Upgrade PCB to KiCad 8 and add interactive HTML bom.
